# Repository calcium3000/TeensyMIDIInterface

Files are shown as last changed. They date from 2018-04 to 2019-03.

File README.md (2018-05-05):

# Teensy MIDI Interface
MIDI interface for the Teensy 3.2 development board

## Hardware
This board provides standard MIDI IN, OUT, and THRU ports that connect to the [PJRC Teensy 3.2](https://www.pjrc.com/teensy/) development board.  Connections follow the MIDI standard -- i.e. optoisolation on the IN port, standard 5mA signals, etc.  For more information, see the [MIDI 1.0 Specification](https://www.midi.org/specifications/item/the-midi-1-0-specification).

In addition, all pins on the perimeter of the Teensy are broken out for easier access and prototyping.  Footprints for a 5V, 1A regulator and associated components are provided for stand-alone operation.

**Warning:** Disconnect external power source when connected to USB.

### Connections
`MIDI_IN` is connected to `D0/RX1` for use with the `Serial1` library.

`MIDI_OUT` is connected to `D1/TX1`, ditto with `Serial1`.

### License
All source files are released under the [TAPR Open Hardware License](http://tapr.org/ohl).  See `LICENSE.txt` for a copy of the license.

## Software
Provided are two test programs for MIDI input and MIDI output configurations.  Both are adopted from [ PRJC's MIDI Library](https://www.pjrc.com/teensy/td_libs_MIDI.html) page.  More specific examples to come!

### License
All source files are released under the [GNU General Public License](https://www.gnu.org/licenses/gpl.html).  See `LICENSE.txt` for a copy of the license.

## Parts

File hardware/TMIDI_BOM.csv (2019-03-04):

QTY | REF DES | VALUE | FOOTPRINT | DESCRIPTION
2 | C1-C2 | 0.1uF | 805 | Capacitor, MLCC, 100V, 10%, X7R
1 | C3 | 1uF | 805 | Capacitor, MLCC, 35V, 10%, X7R
1 | C4 | 4.7uF | 805 | Capacitor, MLCC, 16V, 10%, X7R
1 | C5 | DNP | 805 | Capacitor
2 | D1-D2 | MBR0580S1-7 | SOD-123 | Diode, Schottky, 80V, 500mA
3 | P1-P3 | SDS-50J | Through-hole | Connector, DIN-5, right-angle, PCB mount
2 | P4,P6 | DNP | Socket strip, 2.54mm pitch | Connector, 1x14
1 | P5 | DNP | Socket strip, 2.54mm pitch | Connector, 1x5
1 | P7 | DNP | Socket strip, 2.54mm pitch | Connector, 1x2
5 | R1-R5 | RMCF0805JT220R | 805 | Resistor, thick film, 5%, 0.125W
1 | U1 | TLP2361 | SOIC-5 | Optoisolator, single channel, logic output, inverted
1 | U2 | SN74LV14ADR | SOIC-14 | Logic, inverter, hex, Schmitt trigger
1 | U3 | Teensy 3.2 | Through-hole | Development board, 72MHz, 256kB flash, 64kB RAM
1 | U4 | LDL1117S50R | SOT-223 | Voltage regulator, low-dropout, 5V output, 1.2A

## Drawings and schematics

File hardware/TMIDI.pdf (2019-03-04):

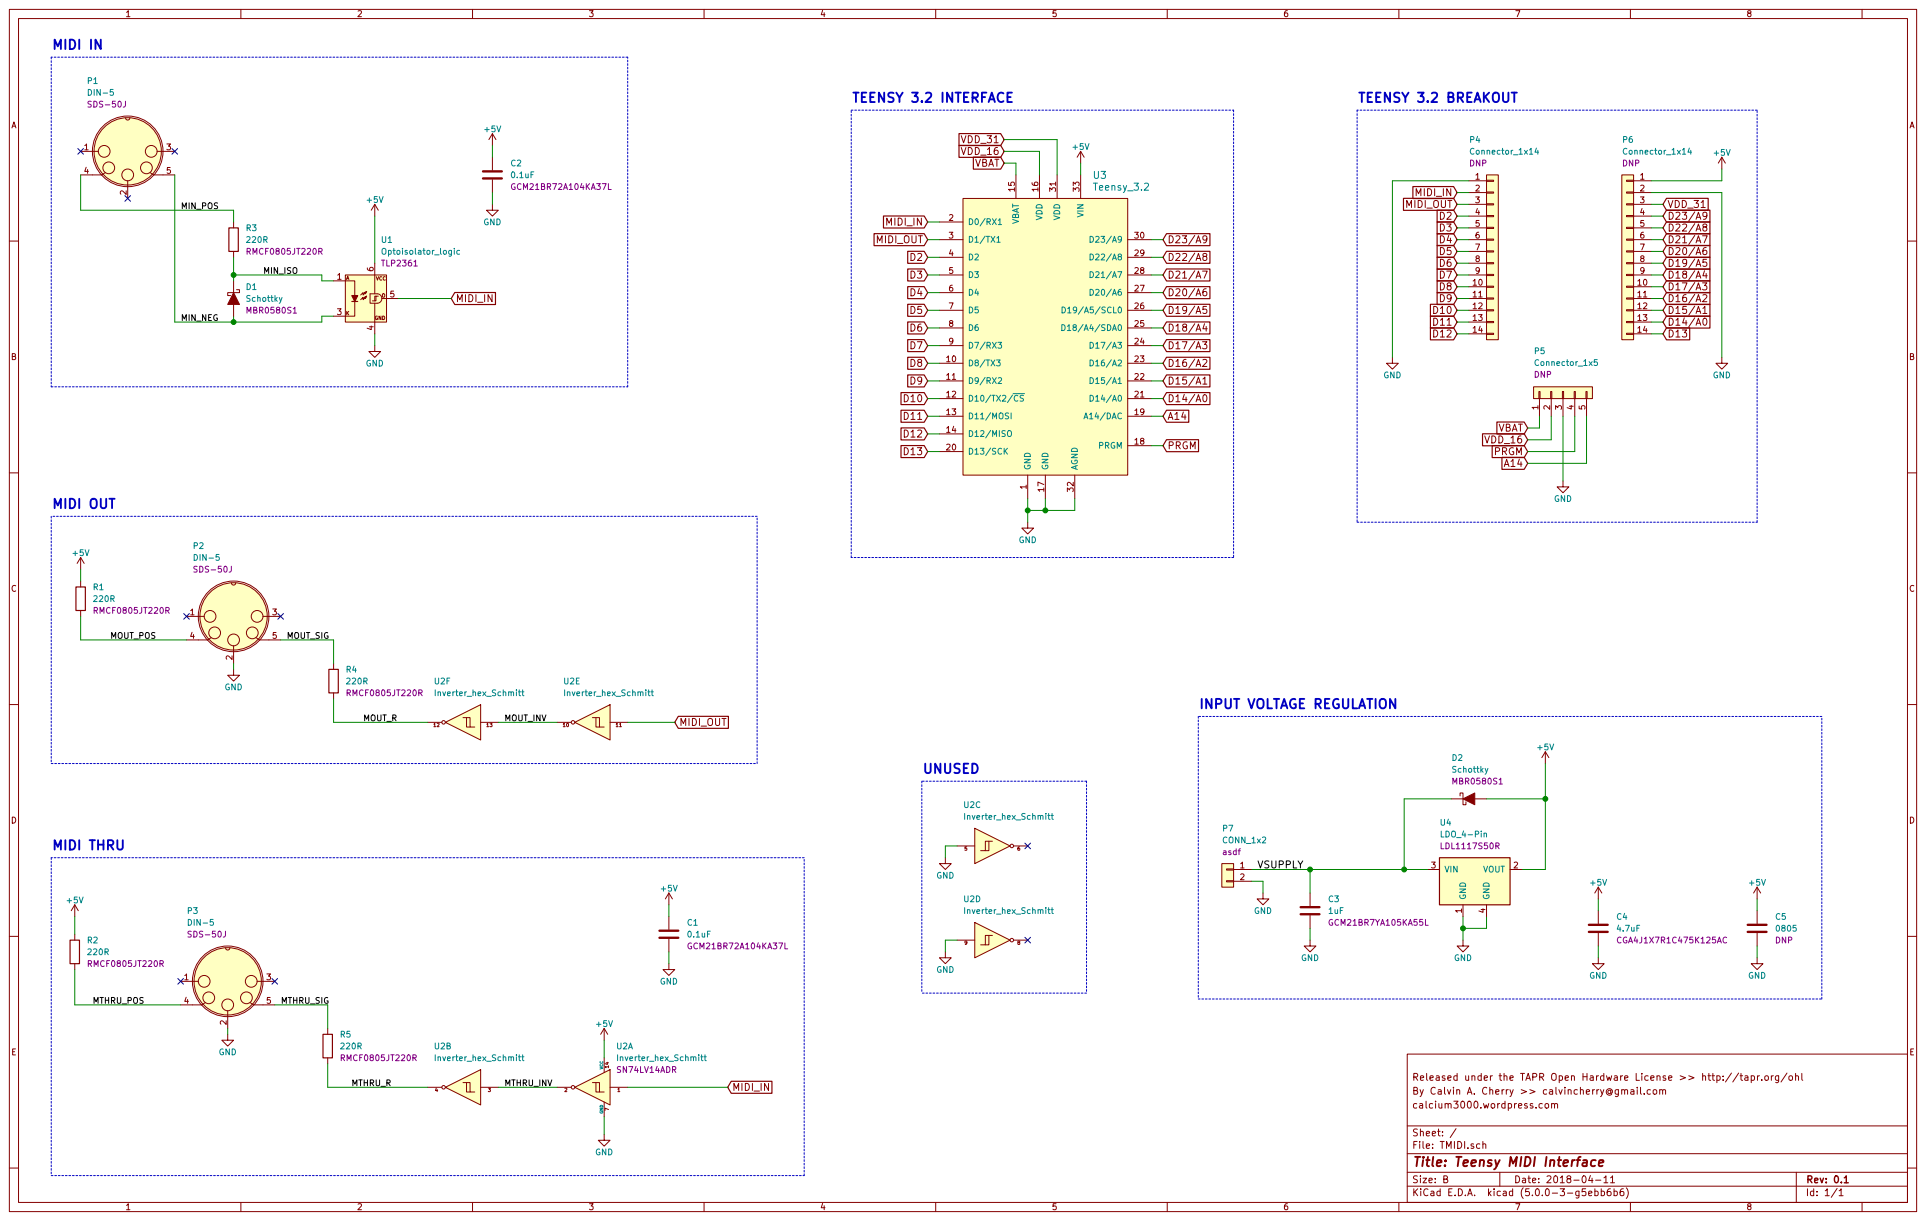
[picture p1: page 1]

1 D0/RX1 2 D1/TX1 3 D2 4 D3 5 D4 6 D5 7 D6 8 D7/RX3 9 D8/TX3 10 D13/SCK 20 D23/A9 30 D9/RX2 11 D14/A0 21 VDD 31 D10/TX2/CS 12 D15/A1 22 AGND 32 D11/MOSI 13 D16/A2 23 VIN 33 D12/MISO 14 D17/A3 24 VBAT 15 D18/A4/SDA0 25 VDD 16 D19/A5/SCL0 26 GND 17 D20/A6 27 PRGM 18 D21/A7 28 A14/DAC 19 D22/A8 29 U3Teensy_3.2 GND D4 D5 D6 D11 D12 D13 D7 D8 D9 D10 D4 D5 D6 D11 D12 GND VBAT VDD_16

Released under the TAPR Open Hardware License >> http://tapr.org/ohl
By Calvin A. Cherry >> calvincherry@gmail.com
File: TMIDI.sch Sheet: / calcium3000.wordpress.com

Id: 1/1 Title: Teensy MIDI Interface

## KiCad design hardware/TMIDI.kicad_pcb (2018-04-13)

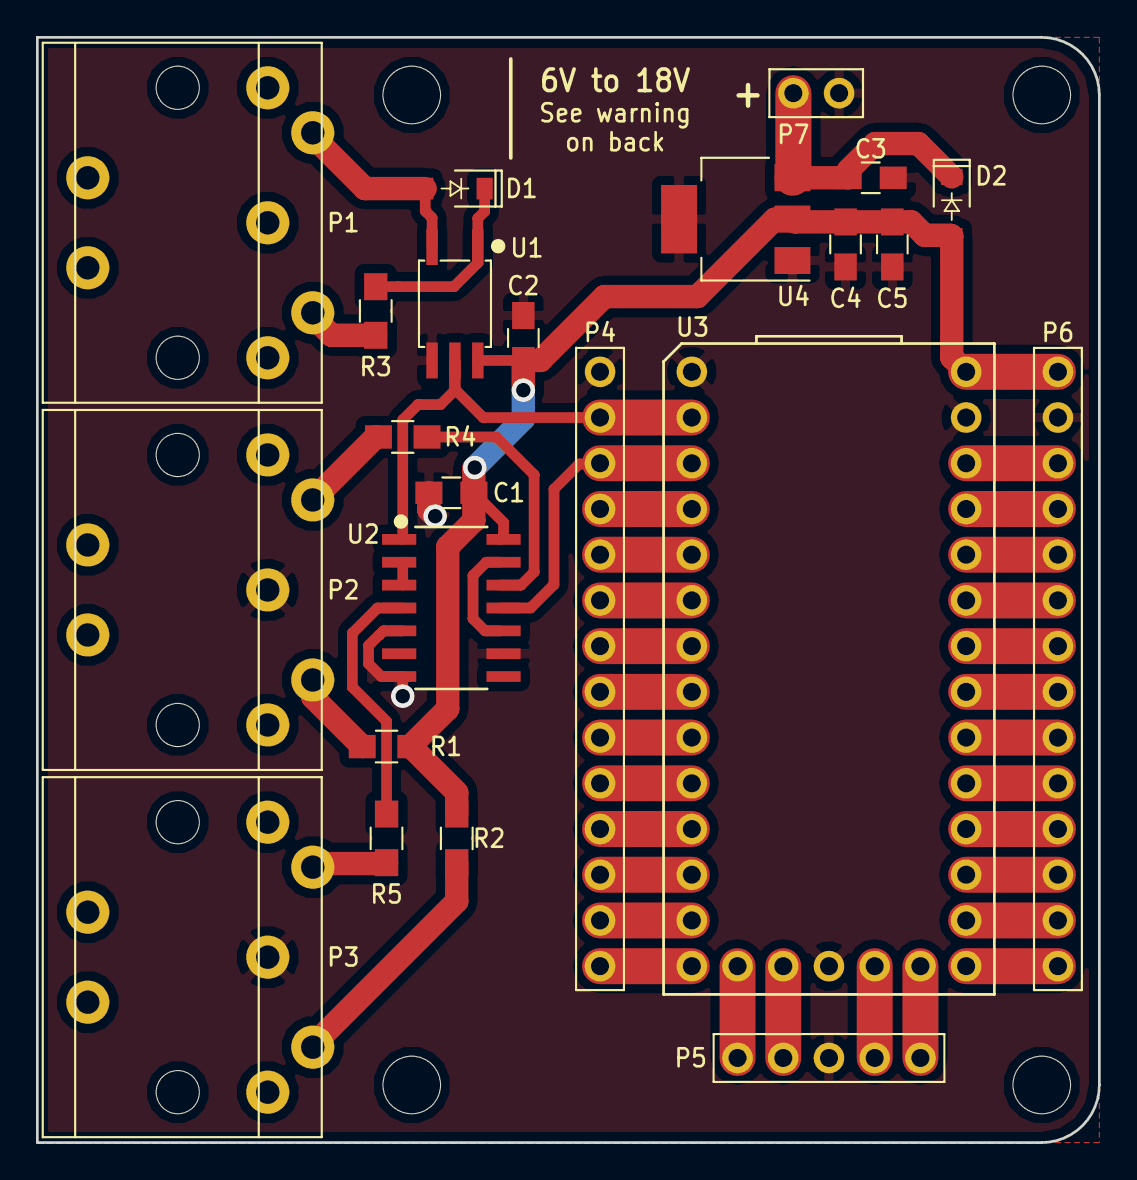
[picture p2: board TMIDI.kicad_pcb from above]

Board: 2 copper layers, 59.0 x 61.4 mm, 27 parts (0 on the bottom side), 43 nets.

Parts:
C1, C2: 0.1uF; C_0805_HandSoldering
C3: 1uF; C_0805_HandSoldering
C4: 4.7uF; C_0805_HandSoldering
C5: 0805; C_0805_HandSoldering
D1: SCHOTTKY; D_SOD-123
D2: D_Schottky; D_SOD-123
MH0, MH1, MH2, MH3: MountingHole_3.2mm_M3_ISO7380
P1, P2, P3: DIN-5; J_DIN-5_RightAngle
P4, P6: CONN_1x14; J_Conn_1x14_Pitch2.54mm
P5: CONN_1x5; J_Conn_1x5_Pitch2.54mm
P7: CONN_1x2; J_Conn_1x2_Pitch2.54mm
R1, R2, R3, R4, R5: 220R; R_0805_HandSoldering
U1: OPTOISOLATOR; U_SO-5_Width6.3mm_Pitch1.27mm
U2: INVERTER_HEX_SCHMITT; U_SOIC-14_Width3.9mm_Pitch1.27mm
U3: Teensy32; U_Teensy3.2
U4: LDO_4-Pin; U_SOT223-4

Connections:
+5V: C1.1, C2.1, C4.1, C5.1, D2.2, P6.1, R1.1, R2.1, U1.6, U2.14, U3.33, U4.2
/MIN_ISO: D1.1, R3.2, U1.1
/MIN_NEG: D1.2, P1.5, U1.3
/MIN_POS: P1.4, R3.1
/MOUT_INV: U2.10, U2.13
/MOUT_POS: P2.4, R1.2
/MOUT_R: R4.2, U2.12
/MOUT_SIG: P2.5, R4.1
/MTHRU_INV: U2.2, U2.3
/MTHRU_POS: P3.4, R2.2
/MTHRU_R: R5.2, U2.4
/MTHRU_SIG: P3.5, R5.1
/VSUPPLY: C3.1, D2.1, P7.1, U4.3
A14: P5.5, U3.19
D2: P4.4, U3.4
D3: P4.5, U3.5
D4: P4.6, U3.6
D5: P4.7, U3.7
D6: P4.8, U3.8
D7: P4.9, U3.9
D8: P4.10, U3.10
D9: P4.11, U3.11
D10: P4.12, U3.12
D11: P4.13, U3.13
D12: P4.14, U3.14
D13: P6.14, U3.20
D14/A0: P6.13, U3.21
D15/A1: P6.12, U3.22
D16/A2: P6.11, U3.23
D17/A3: P6.10, U3.24
D18/A4: P6.9, U3.25
D19/A5: P6.8, U3.26
D20/A6: P6.7, U3.27
D21/A7: P6.6, U3.28
D22/A8: P6.5, U3.29
D23/A9: P6.4, U3.30
GND: C1.2, C2.2, C3.2, C4.2, C5.2, P2.2, P3.2, P4.1, P5.3, P6.2, P7.2, U1.4, U2.5, U2.7, U2.9, U3.1, U3.17, U3.32, U4.1, U4.4
MIDI_IN: P4.2, U1.5, U2.1, U3.2
MIDI_OUT: P4.3, U2.11, U3.3
PRGM: P5.4, U3.18
VBAT: P5.1, U3.15
VDD_16: P5.2, U3.16
VDD_31: P6.3, U3.31

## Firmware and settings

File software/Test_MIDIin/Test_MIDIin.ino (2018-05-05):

/*
 * Test_MIDIin.ino
 * 
 * Copyright 2018  Calvin A. Cherry (calvincherry@gmail.com)
 *                 calcium3000.wordpress.com
 * 
 * Adopted from PRJC's MIDI Library page
 * https://www.pjrc.com/teensy/td_libs_MIDI.html
 * 
 * For use with the Teensy MIDI Interface board
 * https://github.com/calcium3000/TeensyMIDIInterface
 *
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
 * You should have received a copy of the GNU General Public License
 * along with this program; if not, write to the Free Software
 * Foundation, Inc., 51 Franklin Street, Fifth Floor, Boston,
 * MA 02110-1301, USA.
 */

#include <MIDI.h>

#define INACTIVE_MS     10000


MIDI_CREATE_INSTANCE( HardwareSerial, Serial1, MIDI );
unsigned long t = 0;


void setup()
{
  MIDI.begin( MIDI_CHANNEL_OMNI );
  Serial.begin( 57600 );
  Serial.println( "MIDI Input Test" );
}


void loop()
{
  int note, velocity, channel, d1, d2;
  
  if( MIDI.read() )
  {
    byte type = MIDI.getType();
    
    switch( type )
    {
      case midi::NoteOn:
        note = MIDI.getData1();
        velocity = MIDI.getData2();
        channel = MIDI.getChannel();
        if( velocity > 0 )
        {
          Serial.println( String( "Note On:  ch=" ) + channel + ", note=" + note + ", velocity=" + velocity );
        }
        else
        {
          Serial.println( String( "Note Off: ch=" ) + channel + ", note=" + note );
        }
        break;
        
      case midi::NoteOff:
        note = MIDI.getData1();
        velocity = MIDI.getData2();
        channel = MIDI.getChannel();
        Serial.println( String( "Note Off: ch=") + channel + ", note=" + note + ", velocity=" + velocity );
        break;
        
      default:
        d1 = MIDI.getData1();
        d2 = MIDI.getData2();
        Serial.println( String( "Message, type=") + type + ", data = " + d1 + " " + d2 );
    }
    
    t = millis();
  }
  
  if ( millis() - t > INACTIVE_MS )
  {
    t += INACTIVE_MS;
    Serial.println( "(inactivity)" );
  }

  delay( 10 );
}

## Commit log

2018-04-12 Initial commit of v0.1 hardware files
    [TMIDI-B.Cu.gbl, TMIDI-B.Mask.gbs, TMIDI-B.SilkS.gbo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]
2018-04-13 Changed C1-C2 and C4 part numbers, added BOM
    [TMIDI.sch, TMIDI_BOM.csv]
2018-04-13 Removed unused footprints and another pesky .DS_Store file
2018-05-05 Substituted TLP105 (non-inverted output) optoisolator for TLP2361 (inverted output)
    [TMIDI.sch, TMIDI_BOM.csv]
2019-03-04 Updated project to KiCad 5.0, updated optoisolator part number to TLP2361
    [TMIDI.sch, TMIDI_BOM.csv]

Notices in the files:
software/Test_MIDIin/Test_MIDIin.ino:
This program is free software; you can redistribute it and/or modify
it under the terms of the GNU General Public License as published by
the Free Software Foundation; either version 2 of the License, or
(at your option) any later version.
